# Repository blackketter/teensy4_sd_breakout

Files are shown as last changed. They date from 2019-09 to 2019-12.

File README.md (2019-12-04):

A companion sidecar board with microSD connector to mate with the [Teensy 4 Header Breakout Board](https://github.com/blackketter/teensy4_header_breakout).  It's designed to solder to the top 9 pins on the left side of the header breakout.  The 9th pin provides an optional card detect (short the solder bridge) on digital pin 29.

Designed in KiCad.

Notes:

- See also [Combo SD/USB Host breakout](https://github.com/blackketter/teensy4_combo_breakout)
- In progress: First version works great!
- With longer header pins you should be able to flip the board to be under or over the Teensy 4.0
- Uses [Hirose DM3D microSD socket](https://www.digikey.com/product-detail/en/hirose-electric-co-ltd/DM3D-SF/HR1941CT-ND/1786515)
- Added decoupling cap C1, 0.1uF
- Bridge the CARD DETECT jumper to use pin 29 to detect a card in the slot.  Needs INPUT_PULLUP.

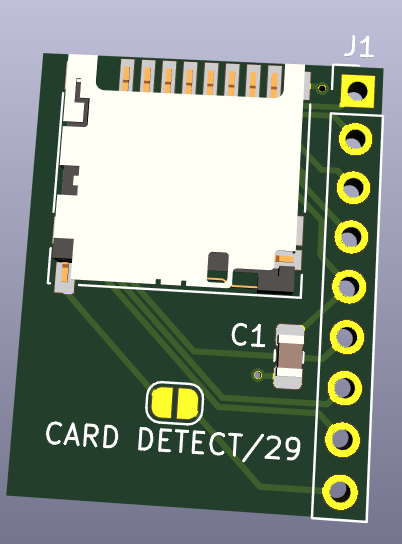
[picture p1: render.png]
breakout render

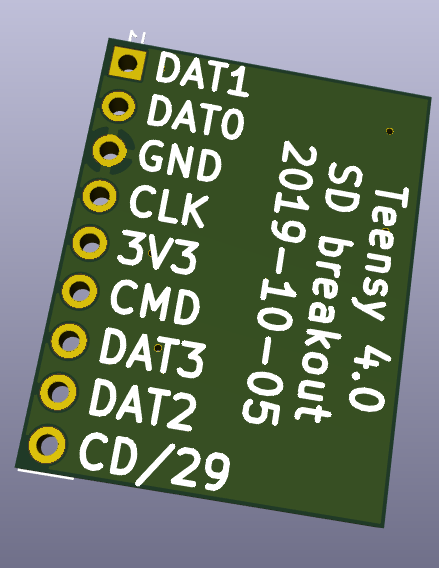
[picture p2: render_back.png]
breakout render_back


Pinout:

1. 34/SD DAT1
2. 35/SD DAT0
3. GND
4. 36/SD CLK
5. 3.3V
6. 37/SD CMD
7. 38/SD DAT3
8. 39/SD DAT2
9. 29/Card Detect

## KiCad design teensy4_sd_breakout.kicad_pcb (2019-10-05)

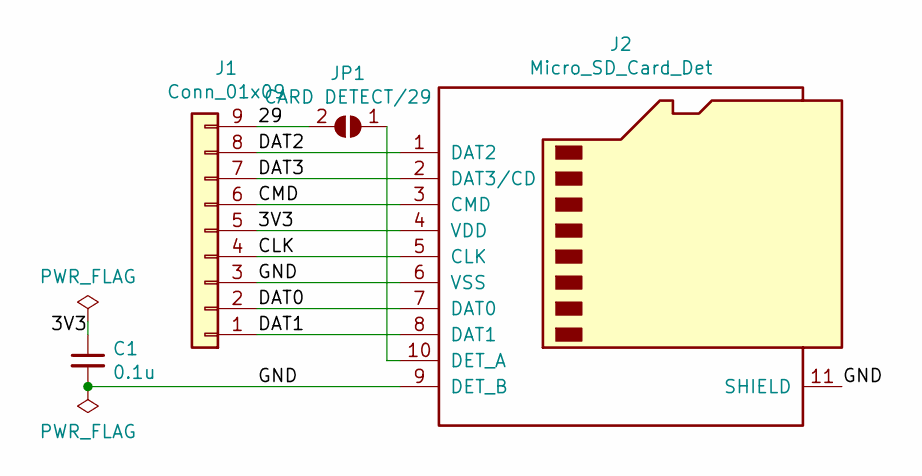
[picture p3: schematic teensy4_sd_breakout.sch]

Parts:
C1: 0.1u; C_0805_2012Metric_Pad1.15x1.40mm_HandSolder
J1: Conn_01x09; PinHeader_1x09_P2.54mm_Vertical
J2: Micro_SD_Card_Det; microSD_HC_Hirose_DM3D-SF
JP1: CARD DETECT/29; SolderJumper-2_P1.3mm_Open_RoundedPad1.0x1.5mm

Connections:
/3V3: C1.1, J1.5, J2.4 (VDD)
/29: J1.9, JP1.2 (B)
/CLK: J1.4, J2.5 (CLK)
/CMD: J1.6, J2.3 (CMD)
/DAT0: J1.2, J2.7 (DAT0)
/DAT1: J1.1, J2.8 (DAT1)
/DAT2: J1.8, J2.1 (DAT2)
/DAT3: J1.7, J2.2 (DAT3/CD)
/GND: C1.2, J1.3, J2.6 (VSS), J2.9 (DET_B), J2.11 (SHIELD)
unnamed: J2.10 (DET_A), JP1.1 (A)

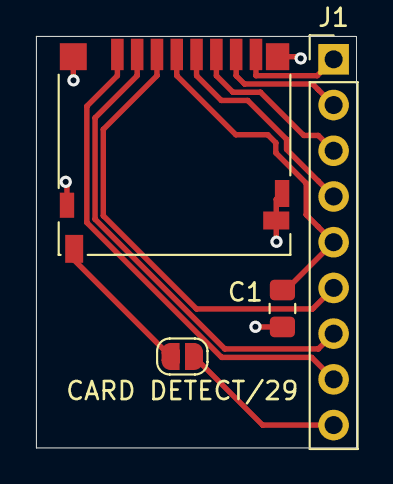
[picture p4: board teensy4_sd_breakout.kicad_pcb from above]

Board: 2 copper layers, 17.8 x 22.9 mm, 4 parts (0 on the bottom side), 10 nets.

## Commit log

2019-09-20 First pass
    [sd_breakout.kicad_pcb, sd_breakout.sch]
2019-09-20 Rename project
    [teensy4_sd_breakout.kicad_pcb, teensy4_sd_breakout.sch]
2019-09-24 Added decoupling cap and back silk screen
    [teensy4_sd_breakout.kicad_pcb, teensy4_sd_breakout.sch]
2019-09-24 Document Card Detect pin
2019-10-05 Updated documentation and silkscreen
    [teensy4_sd_breakout.kicad_pcb, teensy4_sd_breakout.sch]
